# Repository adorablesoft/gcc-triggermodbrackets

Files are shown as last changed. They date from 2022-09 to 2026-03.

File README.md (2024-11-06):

# Brackets For GCC Trigger Mods

3D Models for printing trigger brackets to be used with a variety of alternative trigger mechanisms on a gamecube controller and any additional files such as trigger plugs or modified guard files needed

All of the brackets were designed by referencing my own measurements and community scans of OEM GCC hardware

Thanks for checking it out hope they work well for you

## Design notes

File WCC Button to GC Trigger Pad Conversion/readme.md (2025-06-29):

# Wii Classic Button Pad to GCC Trigger Pad Conversion

Wii Classic Button Pad to GCC Trigger Pad Conversion (For Lighter Press and no perforation needed):

Materials:
9/16 inch Steel Punch (https://a.co/d/5Lm54zA - Thanks to @bacchus for finding and testing this specific one)
3D Printed Cutting Guide In this repository
Wii Classic Button Pad
Scissors/Flush Cutters can be helpful

1. Take the button pad and trim the outer rim flat and even with the rest of the pad so you can easily place the punch wherever needed
2. Take your guide and place it on the pad with the indentation facing down to align on the rubber dome
3. Put the steel punch over the guide on the pad, using light and the hole to look in and verify the guide is centered if you're unsure
4. Apply force to the steel punch to cut through the pad, depending on how hard you are able to press you may need to tear the pad out if you do not manage to fully cut through. This is best done on a very solid surface to avoid damaging materials below the rubber pad such as the table
5. Place in trigger housing as you would with a normal trigger pad.

Additional notes:

There is a very small difference in height of the different domes on the wcc button pad and all are shorter than the OEM GCC Trigger Pads, so be aware that these will not function without trigger plugs as the center of the trigger will not reach the dome.

For simple way of looking at maintaining analog range:
Short Plugs are ~= to No Plug with OEM Pads
Tall Plugs are ~= to Short Plugs on OEM Pads
120% Scale Tall Plugs ~= to Tall Plugs on OEM Pads

Fires tall plugs at 0.9 Z Scale for short and 1.3 Z Scale for tall
Hollow ended plugs carvac made are best at .85 Z scale for short and 1.2 Z scale for tall



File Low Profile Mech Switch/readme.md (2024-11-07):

# Low Profile Mech Switch

This is a brand new version of the file built from the ground up with measurements of switches and scans of original gamecube hardware as guides

The base file is designed for the majority of available varieties of low profile switches, largely the kailh branding

For your install you most likely will need to trim the rumble bracket's arm where it would hold the trigger paddle to make space for wiring, I also recommend using jsts so that when opening the controller you have a much less frustrating experience.

Of the Kailh Switches I recommend Kailh Robins (57gf clicky), as well as Pale Blue (70gf clicky) and Navy (70gf clicky with thicker click bar) with Robins being the standout in my opinion

The KailhV2 Switch version is designed for the newest line of kailh switches which feature very broad stems, which are commonly used for mech triggers

Plugs contains two versions of trigger plugs for use with these brackets, depending on if your switch uses a cross stem like in kailh v2 switches or if you are using some varieties of switches with two pronged wide stems

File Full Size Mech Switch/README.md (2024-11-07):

# Full Size Mech Switch

This is a brand new version of the file built from the ground up with measurements of switches and scans of original gamecube hardware as guides

It is designed to be compatible with any full size mechanical switch like used in most keyboards

Full Size Switch triggers are what I would call a destructive mod, they are too tall to fit in the space of the controller by default and require trimming down the center post of the trigger so that you can fit it inside for the full length press and guaranteed actuation as well as trimming the black rumble bracket arm where it holds the trigger paddle, I generally recommend low profile switches as they do not require the modification to the trigger part itself.

Plugs contains new versions of the stem designs, including a stem designed to be compatible with both mx and box style switches and then a box only variety for the best fit with those switch stems

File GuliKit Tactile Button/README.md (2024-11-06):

# GuliKit Tactile Buttons

These models are to be used with GuliKit Tactile Buttons, which are designed to replicate the general feeling of rubber domes with the goal of being longer lasting

These were made as mostly an experiment but ultimately I found them pretty satisfying as a replacement for a traditional rubber dome digital trigger, they cannot be used for analog as that would require a much more complicated design and likely a two part model that comes together around it

They can be purchased on their own via aliexpress if you're interested in trying them, this model was designed off the 2nd generation design so I cannot guarantee it will work with the 1st generation, these are easily distinguished by the 2nd Gen having an orange stem and the 1st gen having a grey one

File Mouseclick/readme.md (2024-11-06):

# Mouseclick Brackets

There is an option for the bracket with an indentation for a spring to rest in as well as one without

If you intend to use mouseclick with travel for lightshield I recommend using a shorter plug than normal and attaching some rubber to the underside of the plug to reduce the feedback of making contact with the entire mouse switch

The guards folder includes two sets of files, the original full guards as well as a very stripped down model intended mostly for just holding the bracket in place but it is much easier to print, it's also less sturdy but in my tests has held up reasonably well

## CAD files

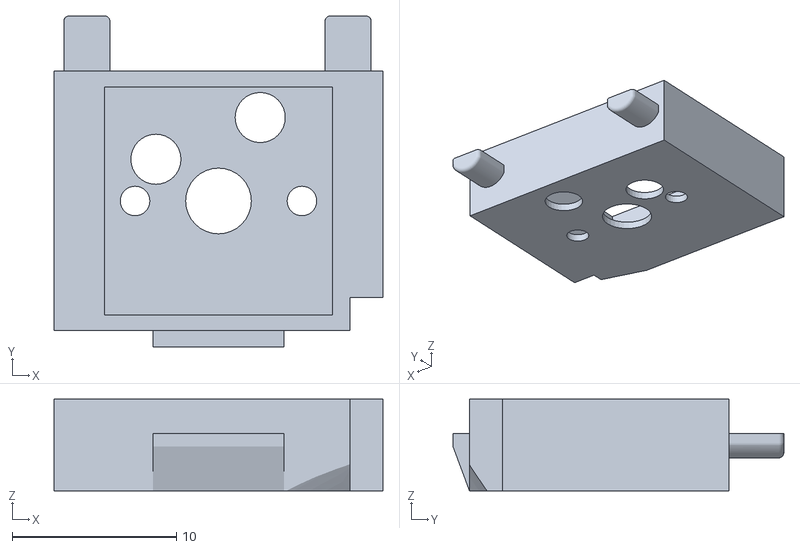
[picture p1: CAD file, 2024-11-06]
Full Size Mech Switch/FullSizeMechRight.stl
20.0 x 20.2 x 5.60

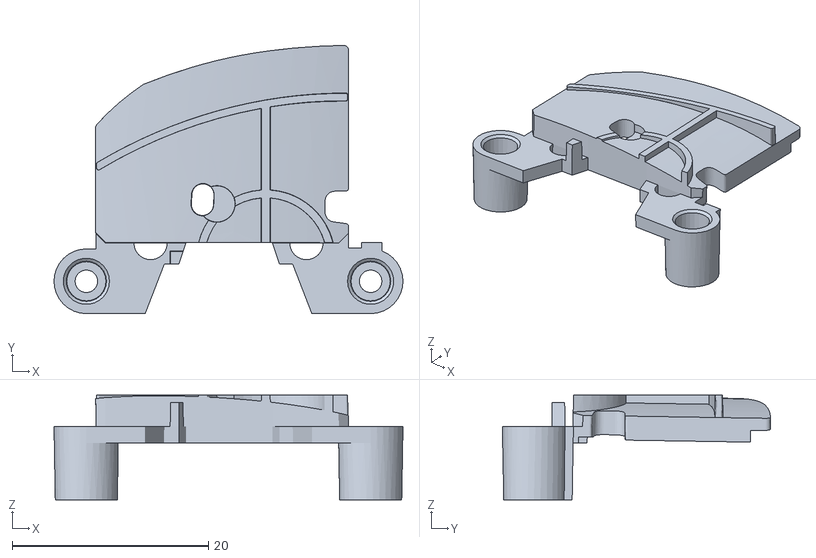
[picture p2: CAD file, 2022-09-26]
Mouseclick/Guards/FullGuardLeft.stl
35.6 x 27.4 x 10.7

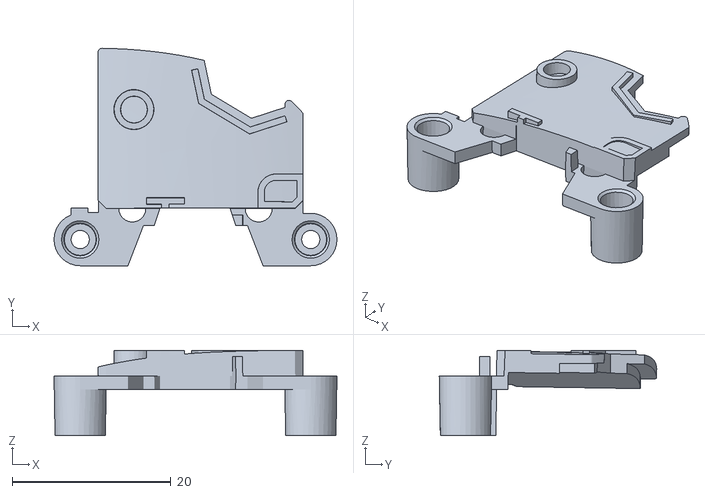
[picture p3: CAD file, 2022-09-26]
Mouseclick/Guards/FullGuardRight.stl
35.6 x 27.4 x 10.7

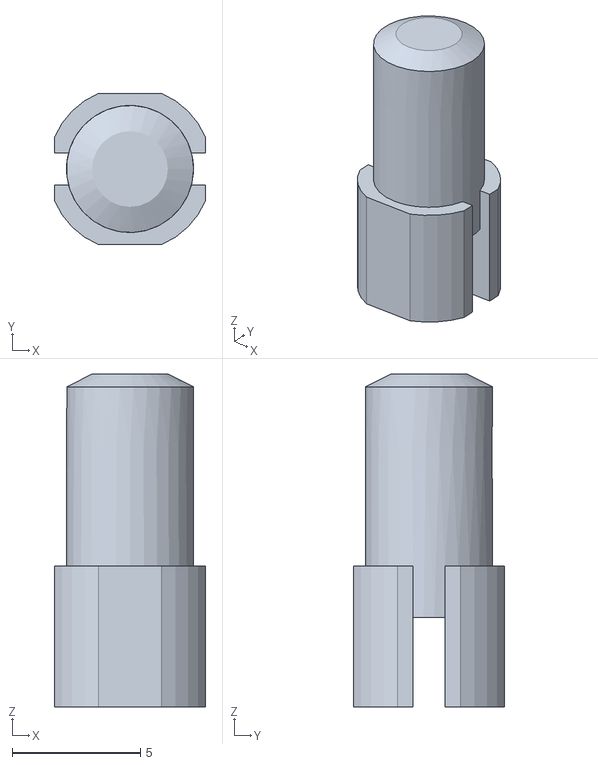
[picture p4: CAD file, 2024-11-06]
Full Size Mech Switch/Plugs/BoxSwitchOnly.stl
5.90 x 5.90 x 13.0

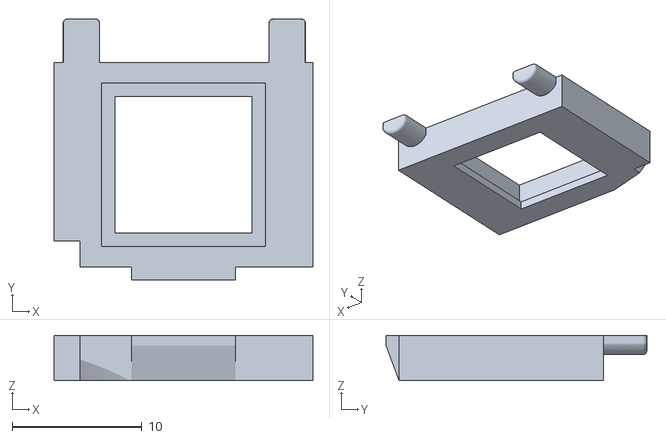
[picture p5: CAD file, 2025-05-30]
GuliKit Tactile Button/GuliKitButtonLeft.stl
20.0 x 20.2 x 3.50

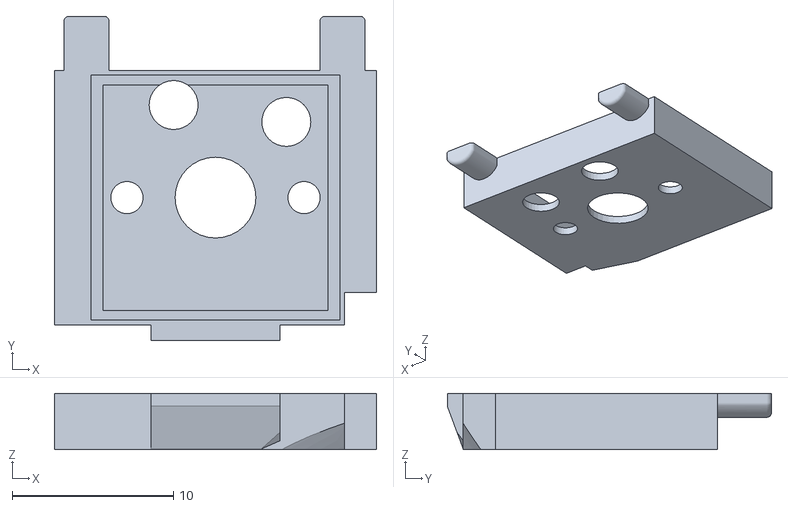
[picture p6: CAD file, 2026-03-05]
Low Profile Mech Switch/GateronLowProfileR.stl
20.0 x 20.2 x 3.50

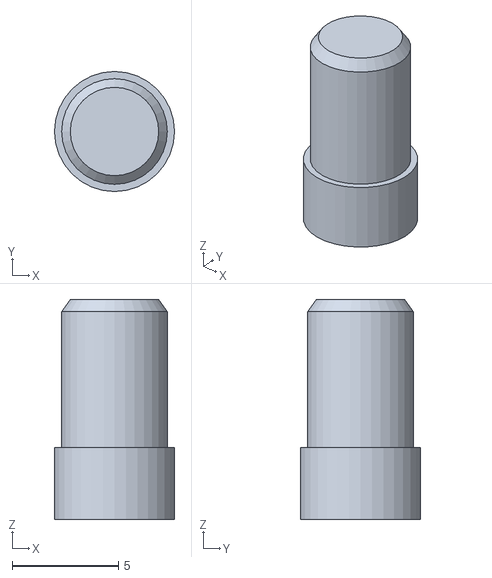
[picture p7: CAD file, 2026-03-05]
Low Profile Mech Switch/Plugs/CrossStemLowProfile.stl
5.66 x 5.66 x 10.4

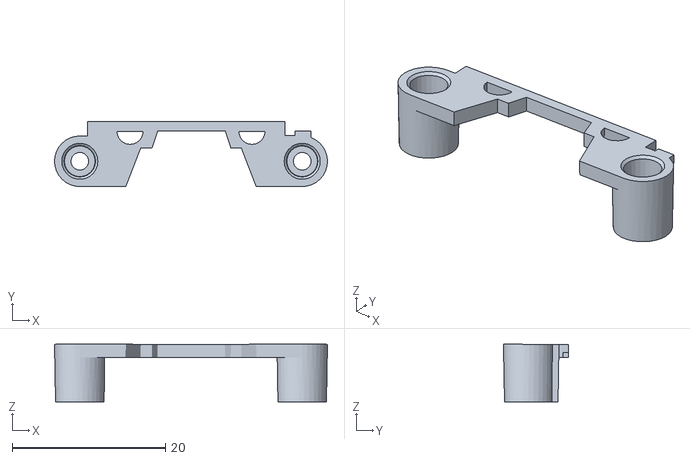
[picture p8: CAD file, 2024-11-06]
Mouseclick/Guards/SlimGuardLeft.stl
35.6 x 8.49 x 7.50

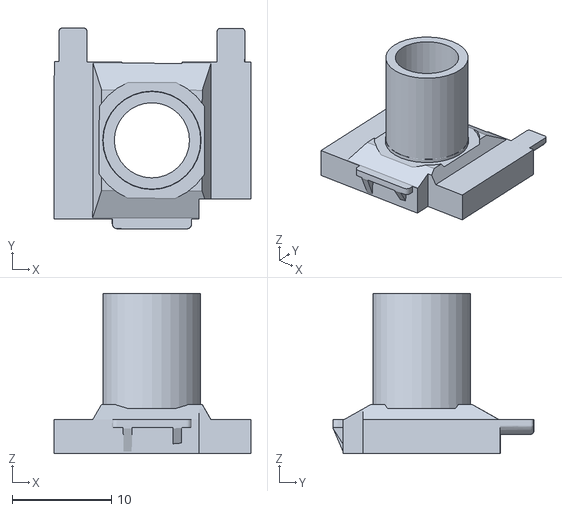
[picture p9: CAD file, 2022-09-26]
Mouseclick/mcbracketrightv3spring.stl
19.8 x 20.2 x 16.1

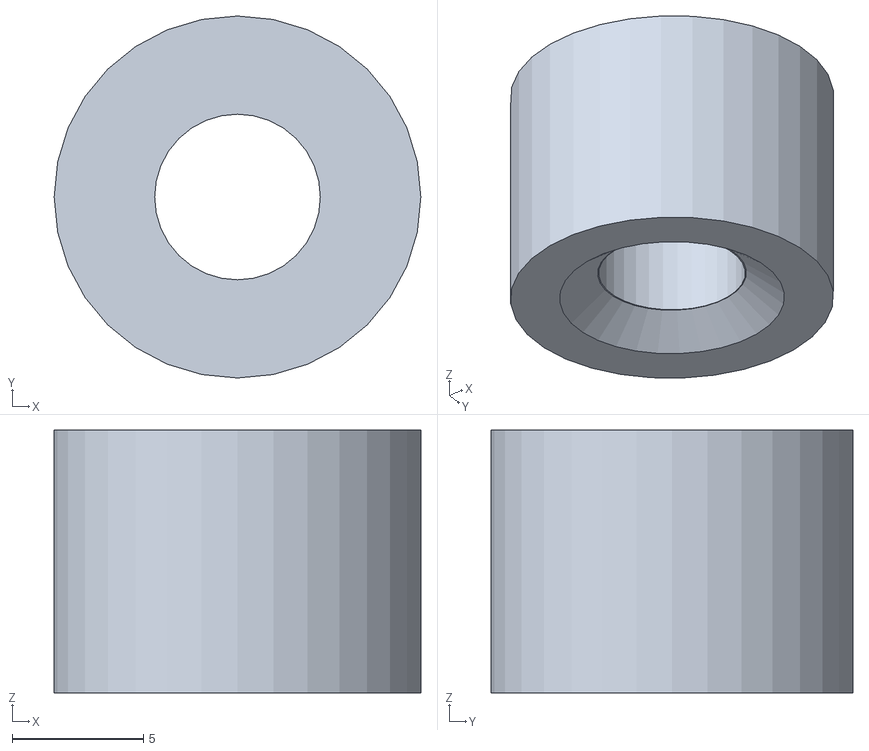
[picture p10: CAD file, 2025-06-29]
WCC Button to GC Trigger Pad Conversion/WCCCutGuide.stl
14.0 x 13.8 x 10.0

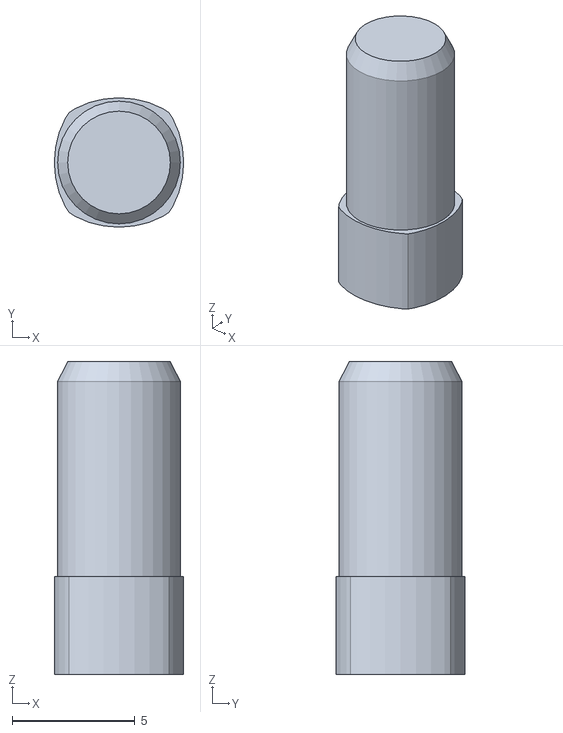
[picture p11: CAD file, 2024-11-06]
GuliKit Tactile Button/GuliKitButtonStem.stl
5.27 x 5.27 x 12.7

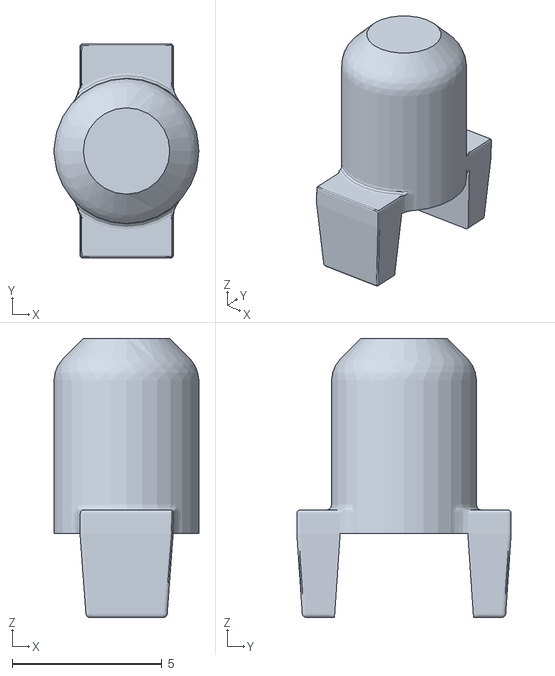
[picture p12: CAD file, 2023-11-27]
Low Profile Mech Switch/Plugs/KailhChocTwoProngStem.stl
4.83 x 7.15 x 9.31

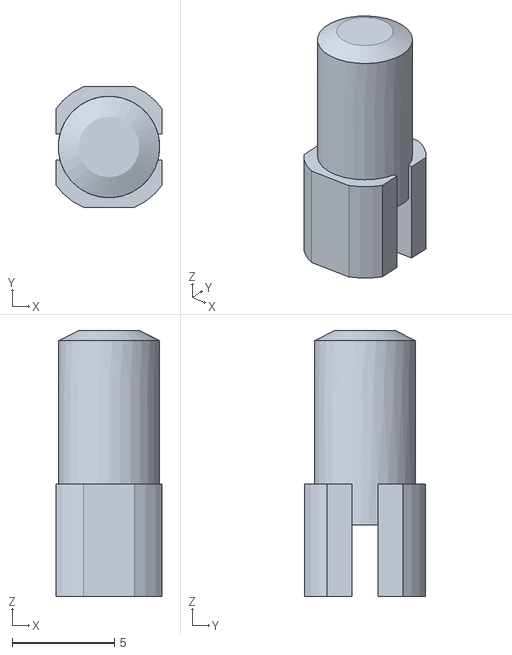
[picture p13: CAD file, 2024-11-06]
Full Size Mech Switch/Plugs/MX&Box.stl
5.20 x 5.90 x 13.0

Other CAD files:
Full Size Mech Switch/FullSizeMechLeft.stl
Full Size Mech Switch/Plugs/BoxSwitchOnlyWalled.stl
Low Profile Mech Switch/LowProfileMechRightKailhV2SwitchLeft.stl
Mouseclick/Guards/SlimGuardRight.stl
Mouseclick/mouseclickbracketrightv3.stl
GuliKit Tactile Button/GuliKitButtonRight.stl
Low Profile Mech Switch/GateronLowProfileL.stl
Low Profile Mech Switch/LowProfileMechLeft.stl
Low Profile Mech Switch/LowProfileMechRight.stl
Low Profile Mech Switch/LowProfileMechRightKailhV2SwitchRight.stl
Mouseclick/mcbracketleftv3spring.stl
Mouseclick/mouseclickbracketleftv3.stl

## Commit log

2022-09-26 Add files via upload
    added files
    [mcbracketleftv3spring.stl, mcbracketrightv3spring.stl, mouseclickbracketleftv3.stl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]
2023-09-20 mech switch triggers
    [kailhindentleft.stl, kailhindentright.stl, mxv2left.stl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]
2023-11-27 Add files via upload
    moved things into folders and added plug files for mech switch triggers
    [cherrymxtriggersstem.stl, kailhindentleft.stl, kailhindentright.stl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]
2025-06-29 Added WCC Conversion Guide model
    [WCCCutGuide.stl]
2025-06-29 change name
    [WCCCutGuide.stl]
2026-03-05 Updates
    Added new brackets for Gateron low profiles due to different pin placement
    Altered Kailh v2 switch brackets for better switch fit after reviewing a dimension change from v1 to v2 I didn't know about previously
    Created a new low profile cross stem plug that should be more durable
    [CrossStemLowProfile.stl, CrossStemPlug.stl, GateronLowProfileL.stl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]
